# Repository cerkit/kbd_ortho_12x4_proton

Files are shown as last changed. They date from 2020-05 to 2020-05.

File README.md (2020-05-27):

# kbd_ortho_12x4_proton (cerkit48)
 12x4 Ortholinear with integrated [Proton C](https://qmk.fm/proton-c/)

 This is my second keyboard design. After finishing my [first design](https://github.com/cerkit/kbd_ortho_12x4), I decided to integrate the [microcontroller](https://qmk.fm/proton-c/) into the board to reduce the amount of wires everywhere and make it more complete.

 This hasn't been tested.

It has a pin header for I2C integration at the top of the board. It's connected to the I2C1 pins on B8 and B9 of the Proton.

Here are the pin connections:

* Row 0: B13
* Row 1: B14
* Row 2: B15
* Row 3: B10
* Col 0: B7
* Col 1: B6
* Col 2: B5
* Col 3: B4
* Col 4: B3
* Col 5: B2
* Col 6: B1
* Col 7: B0
* Col 8: A6
* Col 9: A7
* Col 10: A8
* Col 11: A15

I've created the board firmware as [cerkit48 in my GitHub branch for qmk_firmware](https://github.com/cerkit/qmk_firmware)

Make example for this keyboard (after setting up your build environment):

    make cerkit48:default
    
The copper fill is the ground plane.

Special thanks to [@tzarc](https://github.com/tzarc), [D3vastat0r](https://github.com/covah901), and [zvecr](https://github.com/zvecr) for answering my questions on the QMK Discord.

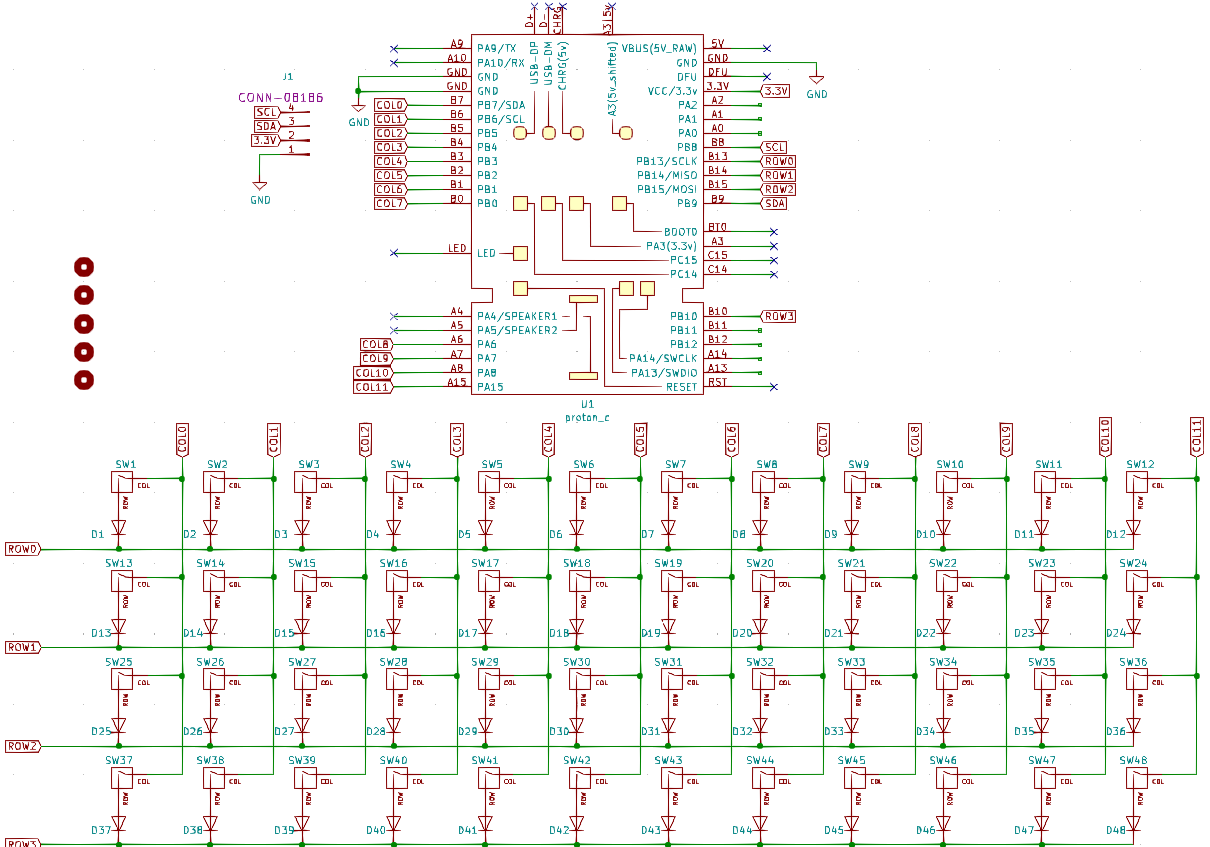
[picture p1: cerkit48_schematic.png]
cerkit48 schematic


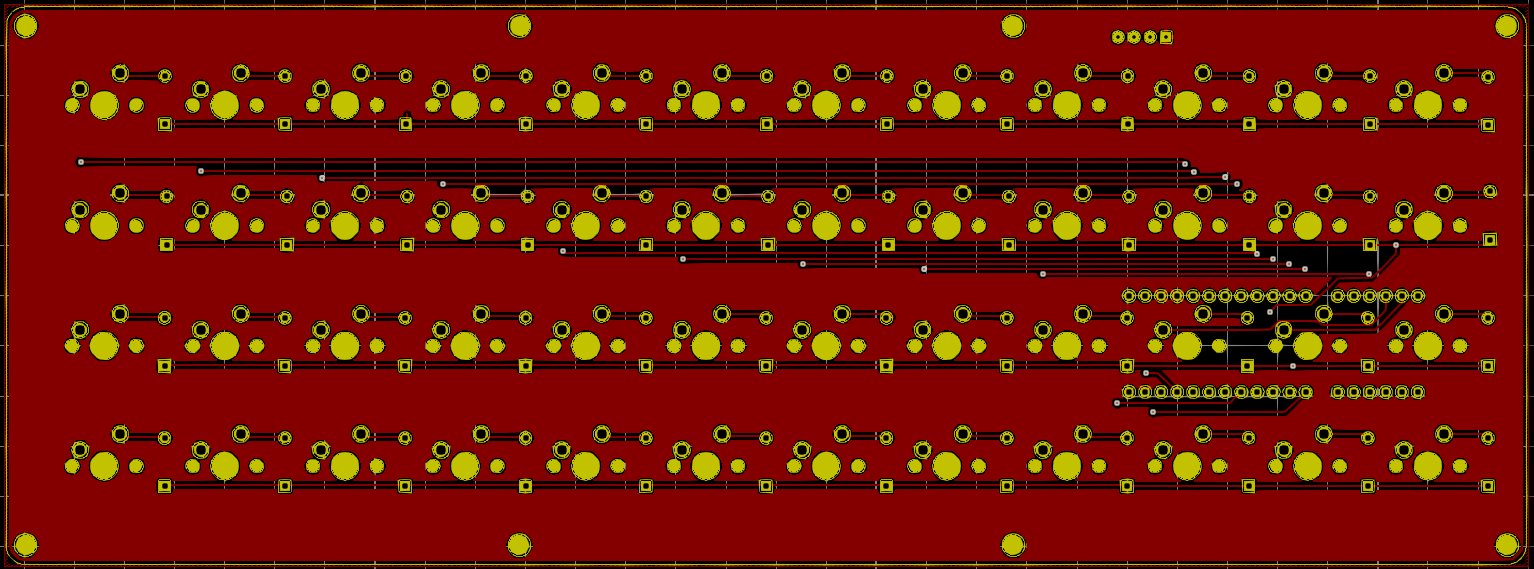
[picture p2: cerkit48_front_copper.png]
cerkit48 front


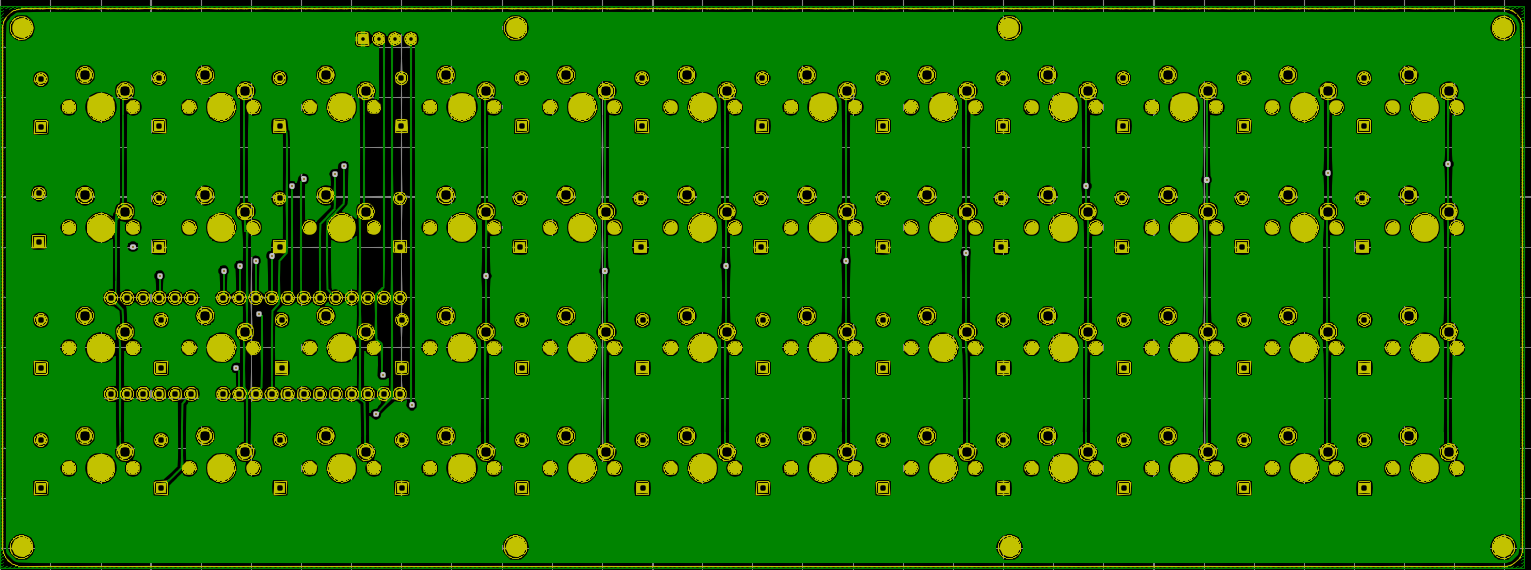
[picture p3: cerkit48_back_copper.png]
cerkit48 back


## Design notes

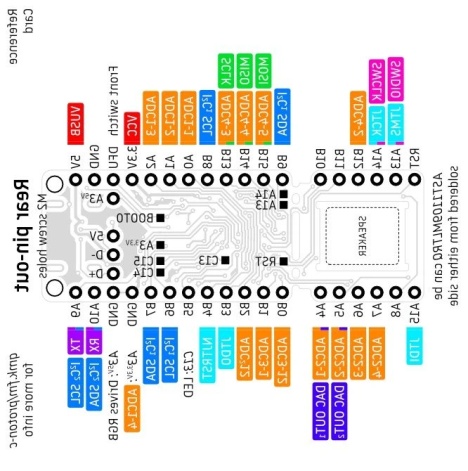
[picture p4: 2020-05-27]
proton-c-pinout_300x300_reversed.png

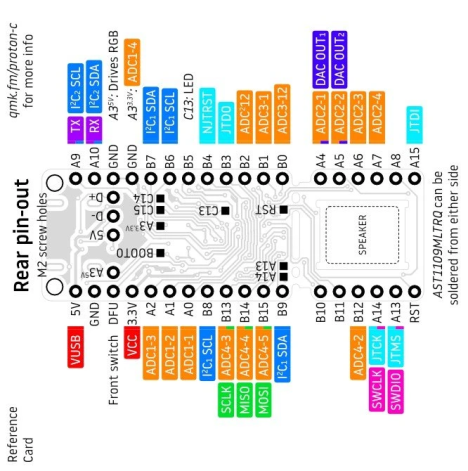
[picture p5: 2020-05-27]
proton-c-pinout_300x300.png

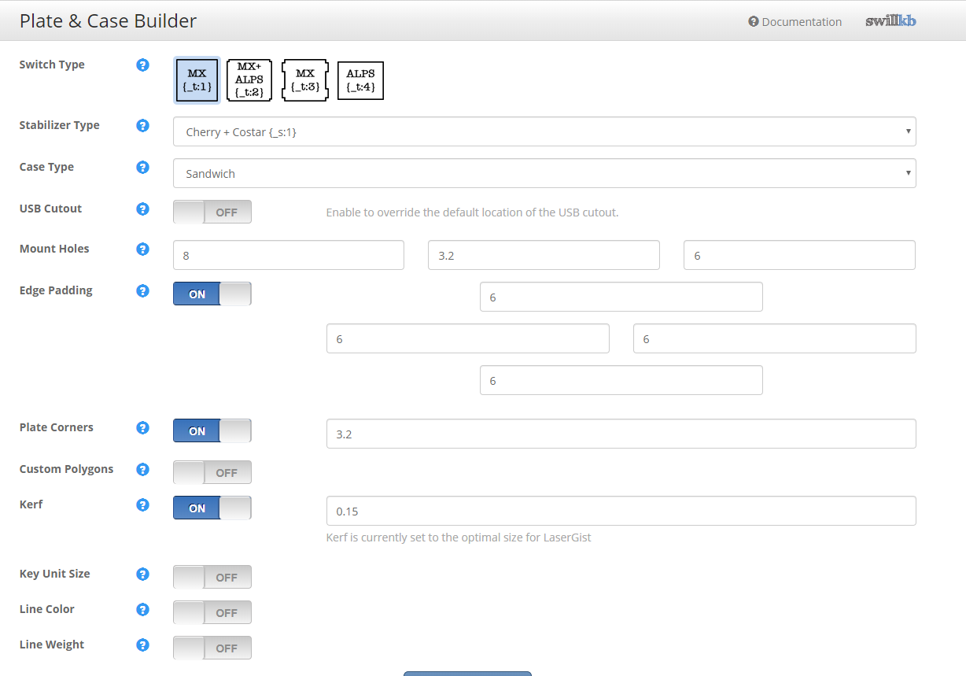
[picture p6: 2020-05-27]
case/case_settings.png

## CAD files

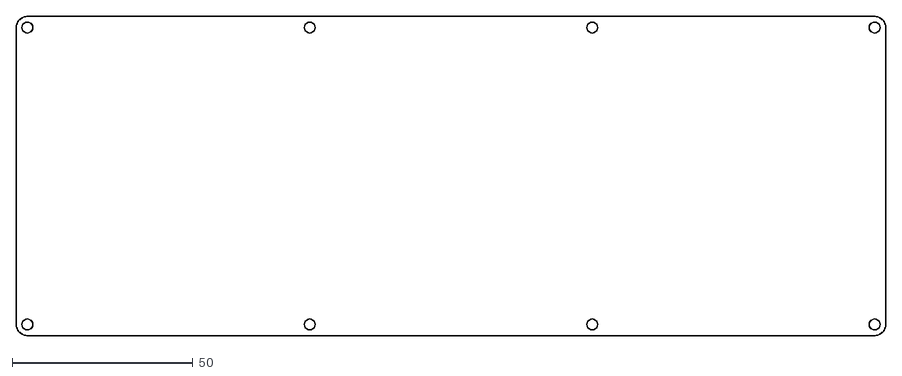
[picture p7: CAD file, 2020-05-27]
case/cerkit48_bottom.dxf
240.8 x 88.4

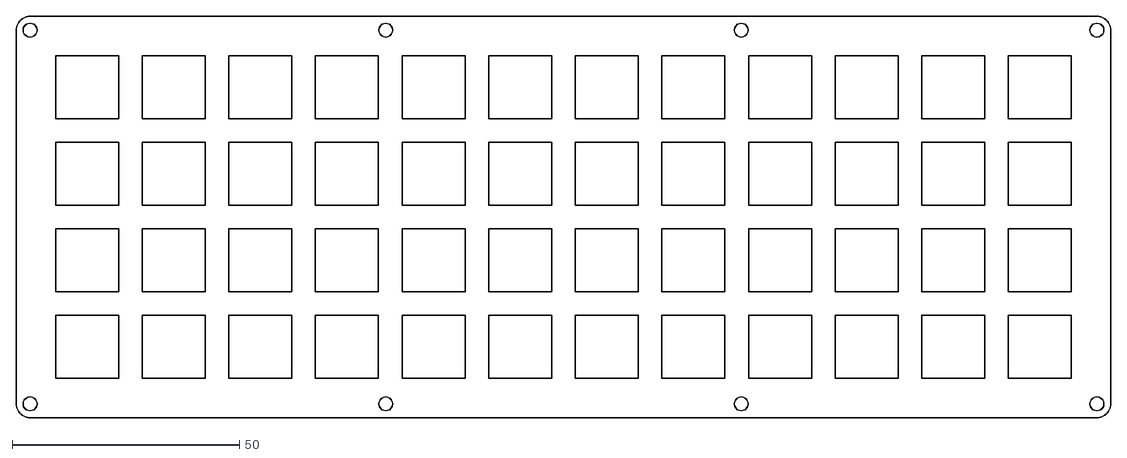
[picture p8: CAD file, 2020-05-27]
case/cerkit48_switch.dxf
240.8 x 88.4

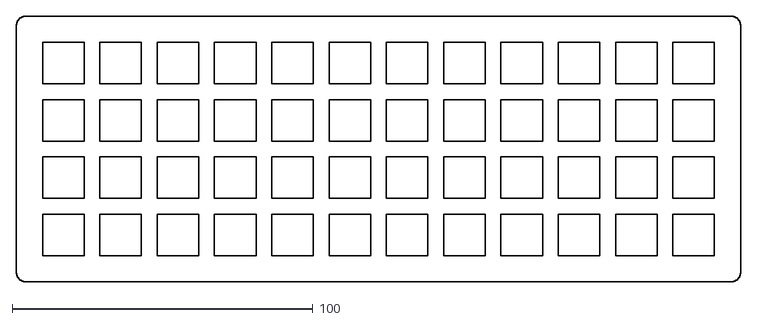
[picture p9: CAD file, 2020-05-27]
case/cerkit48_switch_no_holes.dxf
240.8 x 88.4

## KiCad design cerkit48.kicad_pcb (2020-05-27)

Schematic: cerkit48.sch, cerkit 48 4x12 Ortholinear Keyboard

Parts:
D1, D2, D3, D4, D5, D6, D7, D8, D9, D10, D11, D12, D13, D14, D15, D16, D17, D18, D19, D20, D21, D22, D23, D24, D25, D26, D27, D28, D29, D30, D31, D32, D33, D34, D35, D36, D37, D38, D39, D40, D41, D42, D43, D44, D45, D46, D47, D48: 1N4148; D_DO-35_SOD27_P7.62mm_Horizontal
H1, H2, H3, H4, H5: MountingHole; MountingHole_3.2mm_M3
J1: I2C; PIN_HEADER_I2C
SW1, SW2, SW3, SW4, SW5, SW6, SW7, SW8, SW9, SW10, SW11, SW12, SW13, SW14, SW15, SW16, SW17, SW18, SW19, SW20, SW21, SW22, SW23, SW24, SW25, SW26, SW27, SW28, SW29, SW30, SW31, SW32, SW33, SW34, SW35, SW36, SW37, SW38, SW39, SW40, SW41, SW42, SW43, SW44, SW45, SW46, SW47, SW48: CherryMX; MXOnly-1U-NoLED
U1: proton_c; proton_c_no_center_pins

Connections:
3.3V: J1.2, U1.3.3V (VCC/3.3v)
COL0: SW1.1 (COL), SW13.1 (COL), SW25.1 (COL), SW37.1 (COL), U1.B7 (PB7/SDA)
COL1: SW2.1 (COL), SW14.1 (COL), SW26.1 (COL), SW38.1 (COL), U1.B6 (PB6/SCL)
COL2: SW3.1 (COL), SW15.1 (COL), SW27.1 (COL), SW39.1 (COL), U1.B5
COL3: SW4.1 (COL), SW16.1 (COL), SW28.1 (COL), SW40.1 (COL), U1.B4
COL4: SW5.1 (COL), SW17.1 (COL), SW29.1 (COL), SW41.1 (COL), U1.B3
COL5: SW6.1 (COL), SW18.1 (COL), SW30.1 (COL), SW42.1 (COL), U1.B2
COL6: SW7.1 (COL), SW19.1 (COL), SW31.1 (COL), SW43.1 (COL), U1.B1
COL7: SW8.1 (COL), SW20.1 (COL), SW32.1 (COL), SW44.1 (COL), U1.B0
COL8: SW9.1 (COL), SW21.1 (COL), SW33.1 (COL), SW45.1 (COL), U1.A6
COL9: SW10.1 (COL), SW22.1 (COL), SW34.1 (COL), SW46.1 (COL), U1.A7
COL10: SW11.1 (COL), SW23.1 (COL), SW35.1 (COL), SW47.1 (COL), U1.A8
COL11: SW12.1 (COL), SW24.1 (COL), SW36.1 (COL), SW48.1 (COL), U1.A15
GND: J1.1, U1.GND
unnamed: D1.2 (A), SW1.2 (ROW)
unnamed: D2.2 (A), SW2.2 (ROW)
unnamed: D3.2 (A), SW3.2 (ROW)
unnamed: D4.2 (A), SW4.2 (ROW)
unnamed: D5.2 (A), SW5.2 (ROW)
unnamed: D6.2 (A), SW6.2 (ROW)
unnamed: D7.2 (A), SW7.2 (ROW)
unnamed: D8.2 (A), SW8.2 (ROW)
unnamed: D9.2 (A), SW9.2 (ROW)
unnamed: D10.2 (A), SW10.2 (ROW)
unnamed: D11.2 (A), SW11.2 (ROW)
unnamed: D12.2 (A), SW12.2 (ROW)
unnamed: D13.2 (A), SW13.2 (ROW)
unnamed: D14.2 (A), SW14.2 (ROW)
unnamed: D15.2 (A), SW15.2 (ROW)
unnamed: D16.2 (A), SW16.2 (ROW)
unnamed: D17.2 (A), SW17.2 (ROW)
unnamed: D18.2 (A), SW18.2 (ROW)
unnamed: D19.2 (A), SW19.2 (ROW)
unnamed: D20.2 (A), SW20.2 (ROW)
unnamed: D21.2 (A), SW21.2 (ROW)
unnamed: D22.2 (A), SW22.2 (ROW)
unnamed: D23.2 (A), SW23.2 (ROW)
unnamed: D24.2 (A), SW24.2 (ROW)
unnamed: D25.2 (A), SW25.2 (ROW)
unnamed: D26.2 (A), SW26.2 (ROW)
unnamed: D27.2 (A), SW27.2 (ROW)
unnamed: D28.2 (A), SW28.2 (ROW)
unnamed: D29.2 (A), SW29.2 (ROW)
unnamed: D30.2 (A), SW30.2 (ROW)
unnamed: D31.2 (A), SW31.2 (ROW)
unnamed: D32.2 (A), SW32.2 (ROW)
unnamed: D33.2 (A), SW33.2 (ROW)
unnamed: D34.2 (A), SW34.2 (ROW)
unnamed: D35.2 (A), SW35.2 (ROW)
unnamed: D36.2 (A), SW36.2 (ROW)
unnamed: D37.2 (A), SW37.2 (ROW)
unnamed: D38.2 (A), SW38.2 (ROW)
unnamed: D39.2 (A), SW39.2 (ROW)
unnamed: D40.2 (A), SW40.2 (ROW)
unnamed: D41.2 (A), SW41.2 (ROW)
unnamed: D42.2 (A), SW42.2 (ROW)
unnamed: D43.2 (A), SW43.2 (ROW)
unnamed: D44.2 (A), SW44.2 (ROW)
unnamed: D45.2 (A), SW45.2 (ROW)
unnamed: D46.2 (A), SW46.2 (ROW)
unnamed: D47.2 (A), SW47.2 (ROW)
unnamed: D48.2 (A), SW48.2 (ROW)
ROW0: D1.1 (K), D2.1 (K), D3.1 (K), D4.1 (K), D5.1 (K), D6.1 (K), D7.1 (K), D8.1 (K), D9.1 (K), D10.1 (K), D11.1 (K), D12.1 (K), U1.B13 (PB13/SCLK)
ROW1: D13.1 (K), D14.1 (K), D15.1 (K), D16.1 (K), D17.1 (K), D18.1 (K), D19.1 (K), D20.1 (K), D21.1 (K), D22.1 (K), D23.1 (K), D24.1 (K), U1.B14 (PB14/MISO)
ROW2: D25.1 (K), D26.1 (K), D27.1 (K), D28.1 (K), D29.1 (K), D30.1 (K), D31.1 (K), D32.1 (K), D33.1 (K), D34.1 (K), D35.1 (K), D36.1 (K), U1.B15 (PB15/MOSI)
ROW3: D37.1 (K), D38.1 (K), D39.1 (K), D40.1 (K), D41.1 (K), D42.1 (K), D43.1 (K), D44.1 (K), D45.1 (K), D46.1 (K), D47.1 (K), D48.1 (K), U1.B10
SCL: J1.4, U1.B8
SDA: J1.3, U1.B9

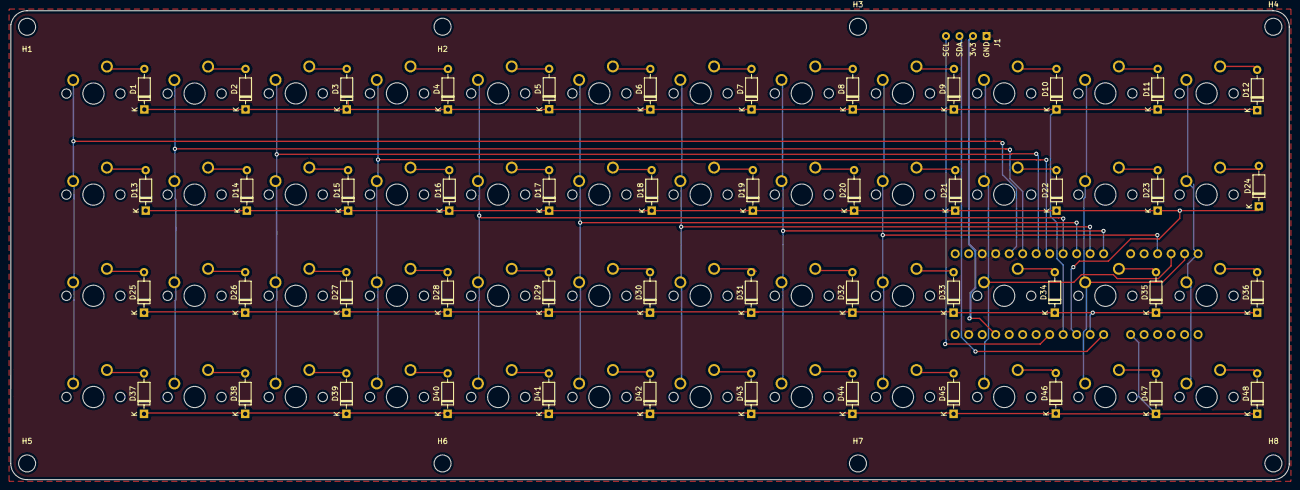
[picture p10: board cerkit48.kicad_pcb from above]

Board: 2 copper layers, 240.7 x 88.3 mm, 106 parts (1 on the bottom side), 68 nets.

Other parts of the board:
H6, H7, H8: MountingHole; MountingHole_3.2mm_M3

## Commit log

2020-05-24 initial checkin
    [cerkit_planck_proton.kicad_pcb, cerkit_planck_proton.sch]
2020-05-24 Added Gerber files
    [cerkit_planck_proton-B_Cu.gbr, cerkit_planck_proton-B_Mask.gbr, cerkit_planck_proton-B_Paste.gbr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]
2020-05-25 added reset button
    [cerkit_planck_proton.kicad_pcb]
2020-05-25 updated gerber with reset button
    [cerkit_planck_proton-B_Cu.gbr, cerkit_planck_proton-B_Mask.gbr, cerkit_planck_proton-B_Paste.gbr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]
2020-05-25 revised images ton include reset button
2020-05-25 added schematic
    [cerkit_planck_proton.kicad_pcb, cerkit_planck_proton.sch]
2020-05-25 renamed KiCad project to reflect new keyboard name
    [cerkit48.kicad_pcb, cerkit48.sch]
2020-05-25 updated schematic
    [cerkit48.sch]
2020-05-25 updated schematic to close some tracks
    [cerkit48.kicad_pcb, cerkit48.sch]
2020-05-25 finished PCB and ran DRC with no errors
    [cerkit48.kicad_pcb, cerkit48.sch]
2020-05-25 Added new I2C Pin Header footprint
    I needed the I2C legend printed on the silkscreen layer, so I made a new footprint.
    [cerkit48.kicad_pcb, cerkit48.sch]
2020-05-25 Add MX submodules
    [cerkit48-B_Cu.gbr, cerkit48-B_Mask.gbr, cerkit48-B_Paste.gbr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]
2020-05-25 Add QMK Hardware submodule
    [cerkit48.kicad_pcb]
2020-05-25 Updated schematic details and footprint references
    [cerkit48.sch]
2020-05-25 Updated schematic to use project symbols from submodules
    [cerkit48-B_Cu.gbr, cerkit48-B_Mask.gbr, cerkit48-B_Paste.gbr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]
2020-05-25 reworked back traces
    [cerkit48.kicad_pcb, cerkit48.sch]
2020-05-26 reworked front traces
    [cerkit48.kicad_pcb]
2020-05-26 shrank the board size
    [cerkit48.kicad_pcb]
2020-05-26 fixed unconnected diode
    [cerkit48.kicad_pcb]
2020-05-26 reworked diodes so the board could be smaller
    [cerkit48.kicad_pcb, cerkit48.sch]
2020-05-27 Move proton (#2)
    * Move Proton to bottom of board and made board smaller
    * Added Proton Pinout diagram
    * flipped Proton so it will be arranged correctly on the back of the board.
    * Updated reame and fixed stray trace in PCB
    * Reworked switches so that they lined up to the grid
    * cleaned up PCB
    * Update proton-c-pinout_300x300.png
    * updated PCB and images
    * rounded the edges of the board
    * rounded the edges of the PCB
    * modified gerber files
    * fixed PCB outline
    [cerkit48-B_Cu.gbl, cerkit48-B_Cu.gbr, cerkit48-B_Mask.gbr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]
2020-05-27 centered middle mounting hole
    [cerkit48.kicad_pcb]
2020-05-27 reset switch number annotations
    [cerkit48.kicad_pcb, cerkit48.sch]
2020-05-27 adjusted outline so that standoffs would fit
    [cerkit48.kicad_pcb]
2020-05-27 added extra mounting holes and a top and bottom plate
    [cerkit48.kicad_pcb, cerkit48.sch, cerkit48_bottom.dxf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]
